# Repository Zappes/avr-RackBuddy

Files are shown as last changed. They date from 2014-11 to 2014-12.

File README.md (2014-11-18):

Der RackBuddy
============

Was isses?
-------------

Der RackBuddy ist ein Dingsbums für mein Serverrack, das Temperaturen misst, sie auf 7-Segment-Anzeigen ausgibt und per USB an den Rechner meldet.

Zum RackBuddy gibt es auch ein paar Videos, und zwar hier:

 - [Playlist bei Youtube](http://www.youtube.com/playlist?list=PLFFlJlvZ--PkYDAD19FQtcRBbY8yCnrR-)

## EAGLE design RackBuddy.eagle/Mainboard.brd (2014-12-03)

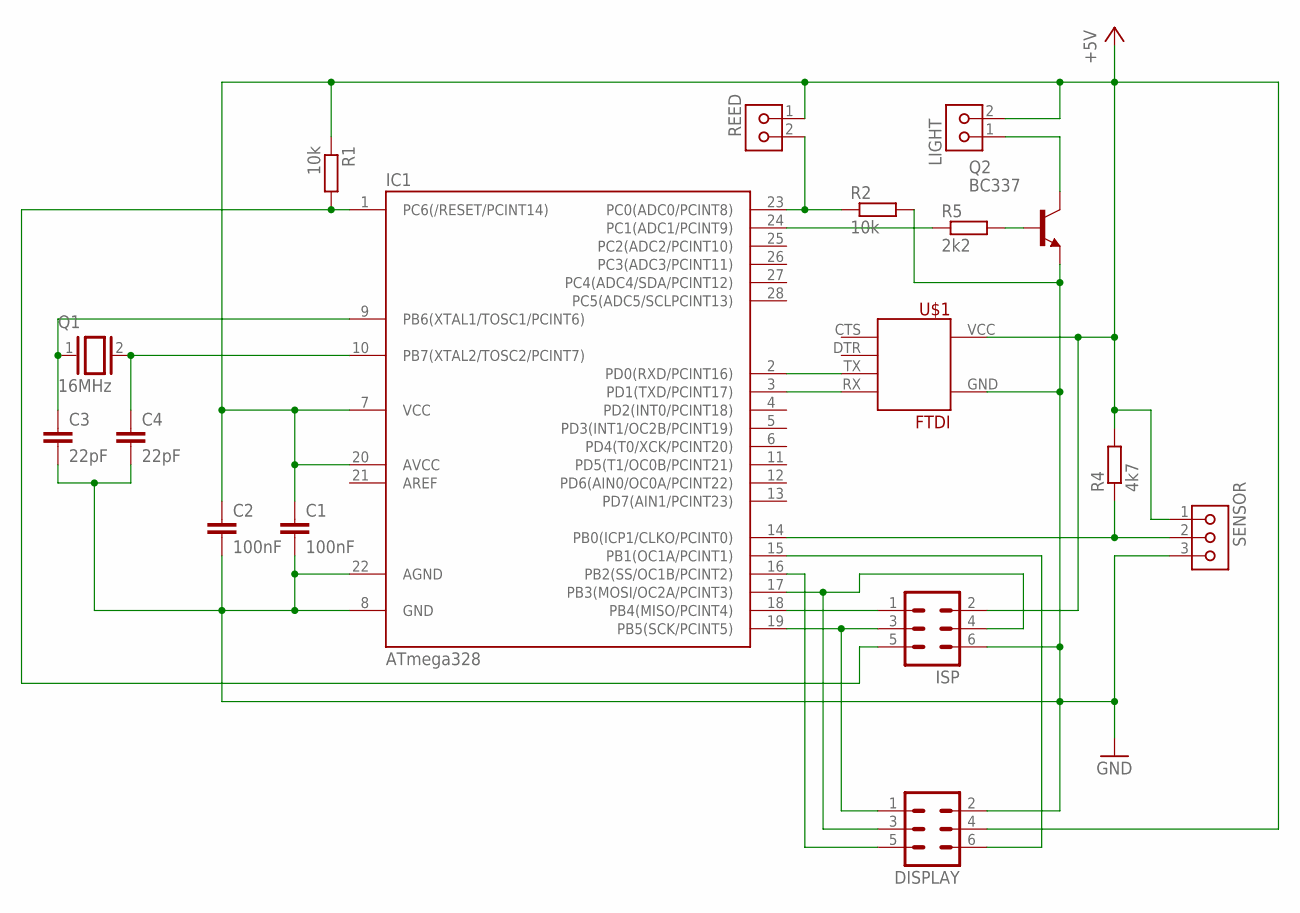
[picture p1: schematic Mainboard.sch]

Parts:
C1: 100nF; C050-025X075
C2: 100nF; C025-025X050
C3, C4: 22pF; C025-025X050
DISPLAY: ML6
IC1: ATmega328; DIL28-3
ISP: ML6
LIGHT: KK2VSQ; KK-V-2-SQ
Q1: 16MHz; QS
Q2: BC337; TO92-STRAIGHT-0.254
R1: 10k; 0207/10
R2: 10k; 0204V
R4: 4k7; 0204/7
R5: 2k2; 0204/7
REED: KK2VSQ; KK-V-2-SQ
SENSOR: KK3V; KK-V-3
U$1: FTDI; FTDI-1

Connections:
+5V: C1.1, C2.1, DISPLAY.4, IC1.7 (VCC), IC1.20 (AVCC), ISP.2, LIGHT.2, R1.1, R4.2, REED.1, SENSOR.1, U$1.VCC (+5V)
GND: C1.2, C2.2, C3.2, C4.2, DISPLAY.2, IC1.8 (GND), IC1.22 (AGND), ISP.6, Q2.3 (E), R2.2, SENSOR.3, U$1.GND
unnamed: Q2.2 (B), R5.2
unnamed: IC1.24 (PC1(ADC1/PCINT9)), R5.1
unnamed: IC1.2 (PD0(RXD/PCINT16)), U$1.TX
unnamed: IC1.3 (PD1(TXD/PCINT17)), U$1.RX
unnamed: C3.1, IC1.9 (PB6(XTAL1/TOSC1/PCINT6)), Q1.1
unnamed: C4.1, IC1.10 (PB7(XTAL2/TOSC2/PCINT7)), Q1.2
unnamed: DISPLAY.3, IC1.17 (PB3(MOSI/OC2A/PCINT3)), ISP.4
unnamed: IC1.1 (PC6(/RESET/PCINT14)), ISP.5, R1.2
unnamed: IC1.23 (PC0(ADC0/PCINT8)), R2.1, REED.2
unnamed: IC1.14 (PB0(ICP1/CLKO/PCINT0)), R4.1, SENSOR.2
unnamed: LIGHT.1, Q2.1 (C)
unnamed: DISPLAY.5, IC1.16 (PB2(SS/OC1B/PCINT2))
unnamed: IC1.18 (PB4(MISO/PCINT4)), ISP.1
unnamed: DISPLAY.1, IC1.19 (PB5(SCK/PCINT5)), ISP.3
unnamed: DISPLAY.6, IC1.15 (PB1(OC1A/PCINT1))

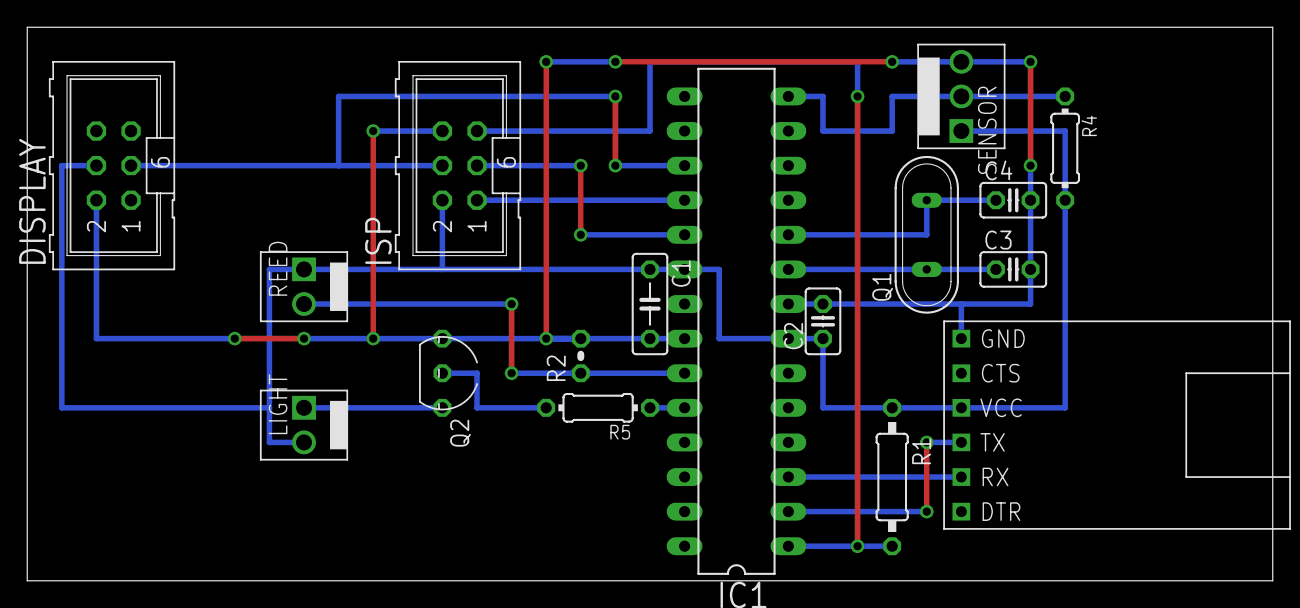
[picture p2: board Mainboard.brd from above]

Board: 3 copper layers, 91.4 x 40.6 mm, 17 parts (0 on the bottom side), 17 nets.

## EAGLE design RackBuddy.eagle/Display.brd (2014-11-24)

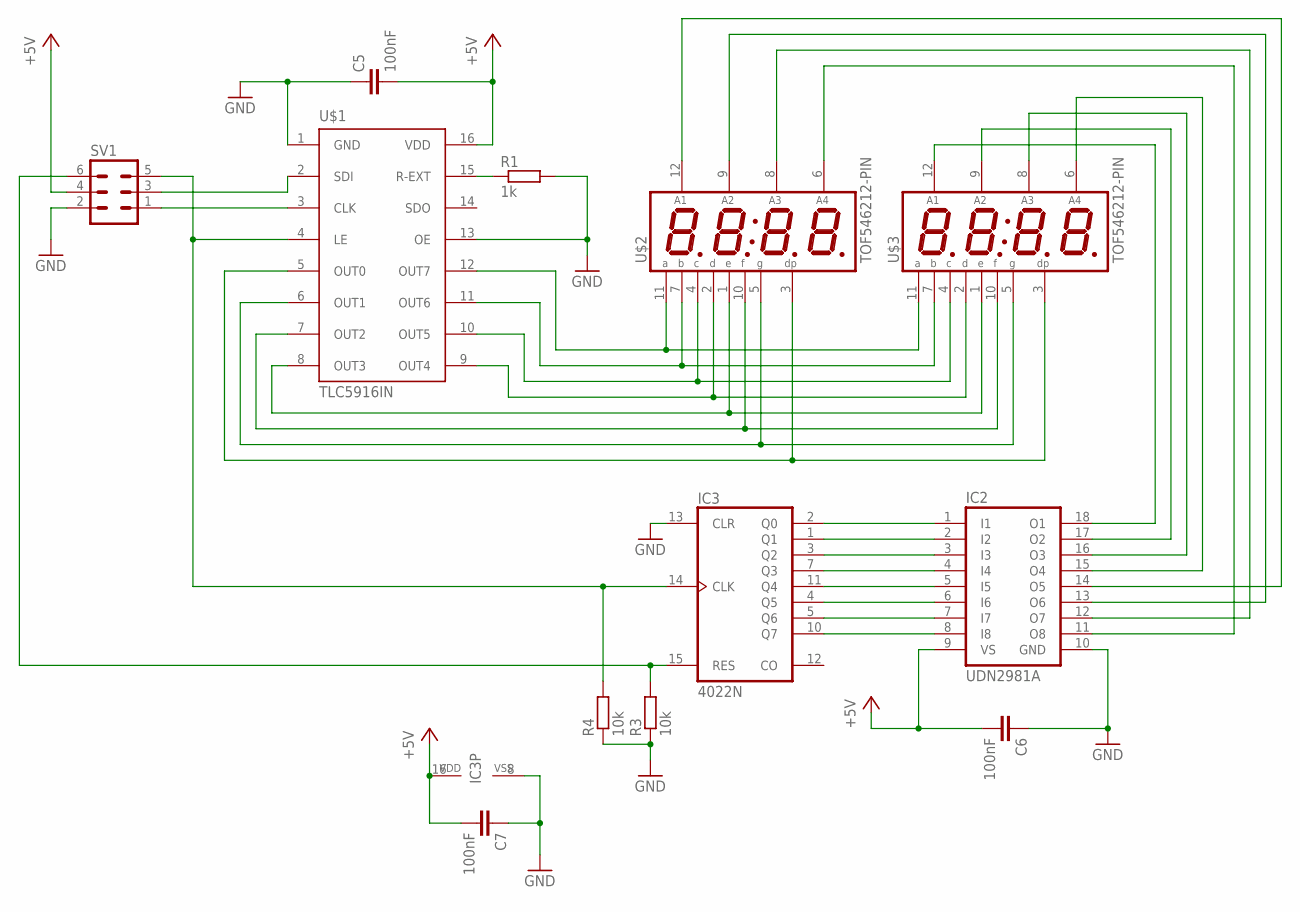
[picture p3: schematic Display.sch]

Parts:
C5, C6, C7: 100nF; C025-024X044
IC2: UDN2981A; DIL18
IC3: 4022N; DIL16
R1: 1k; 0204/7
R3, R4: 10k; 0204V
SV1: ML6L
U$1: TLC5916IN; DIL16
U$2, U$3: TOF546212-PIN; TOF5462*

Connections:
+5V: C5.2, C6.2, C7.2, IC2.9 (VS), IC3.16 (VDD), SV1.4, U$1.16 (VDD)
CLOCK: SV1.1, U$1.3 (CLK)
DATA: SV1.3, U$1.2 (SDI)
GND: C5.1, C6.1, C7.1, IC2.10 (GND), IC3.8 (VSS), IC3.13 (CLR), R1.2, R3.1, R4.1, SV1.2, U$1.1 (GND), U$1.13 (OE)
LATCH: IC3.14 (CLK), R4.2, SV1.5, U$1.4 (LE)
unnamed: U$1.11 (OUT6), U$2.7 (B), U$3.7 (B)
unnamed: IC2.17 (O2), U$3.9 (A2)
unnamed: U$1.10 (OUT5), U$2.4 (C), U$3.4 (C)
unnamed: U$1.9 (OUT4), U$2.2 (D), U$3.2 (D)
unnamed: R1.1, U$1.15 (R-EXT)
unnamed: U$1.8 (OUT3), U$2.1 (E), U$3.1 (E)
unnamed: U$1.7 (OUT2), U$2.10 (F), U$3.10 (F)
unnamed: U$1.6 (OUT1), U$2.5 (G), U$3.5 (G)
unnamed: U$1.5 (OUT0), U$2.3 (DP), U$3.3 (DP)
unnamed: IC2.1 (I1), IC3.2 (Q0)
unnamed: IC2.2 (I2), IC3.1 (Q1)
unnamed: IC2.3 (I3), IC3.3 (Q2)
unnamed: IC2.4 (I4), IC3.7 (Q3)
unnamed: IC2.5 (I5), IC3.11 (Q4)
unnamed: IC2.6 (I6), IC3.4 (Q5)
unnamed: IC2.7 (I7), IC3.5 (Q6)
unnamed: IC2.8 (I8), IC3.10 (Q7)
unnamed: IC2.18 (O1), U$3.12 (A1)
unnamed: IC2.14 (O5), U$2.12 (A1)
unnamed: U$1.12 (OUT7), U$2.11 (A), U$3.11 (A)
unnamed: IC2.13 (O6), U$2.9 (A2)
unnamed: IC2.16 (O3), U$3.8 (A3)
unnamed: IC2.12 (O7), U$2.8 (A3)
unnamed: IC2.15 (O4), U$3.6 (A4)
unnamed: IC2.11 (O8), U$2.6 (A4)
RESET: IC3.15 (RES), R3.2, SV1.6

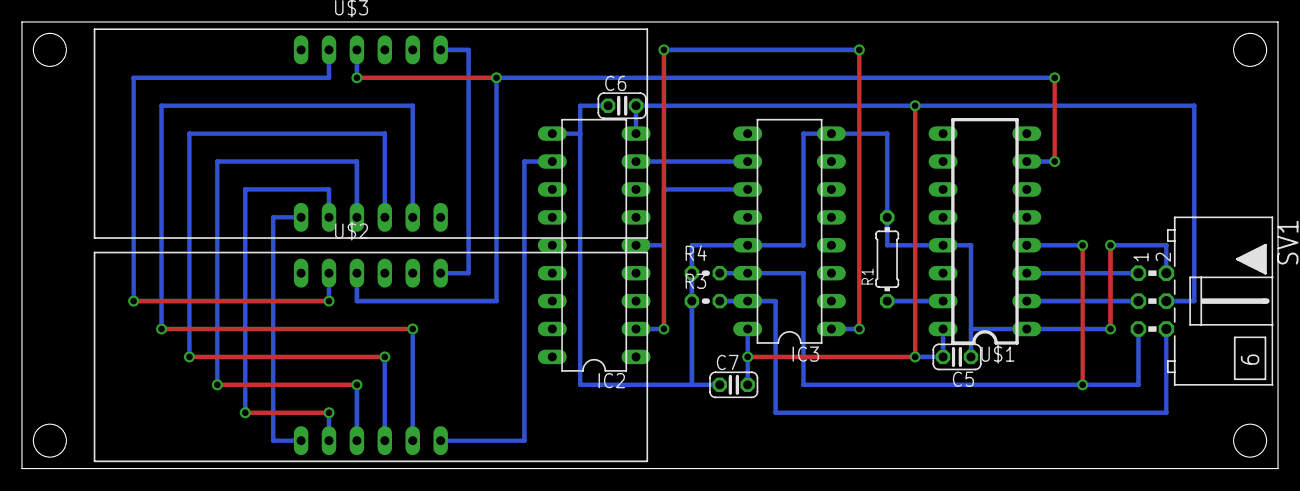
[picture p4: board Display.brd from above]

Board: 2 copper layers, 114.3 x 40.6 mm, 12 parts (0 on the bottom side), 31 nets.

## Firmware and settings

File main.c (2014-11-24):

/*
 * Controller code for a device that reads analog sensor values and sleeps
 * while it isn't used. Check the README at Github for more information.
 *
 * Written by Gregor Ottmann, https://github.com/Zappes
 */
#include <avr/io.h>
#include <avr/interrupt.h>
#include <util/delay.h>
#include <stdio.h>

#include "lib/display.h"
#include "lib/uart.h"
#include "lib/onewire.h"
#include "lib/ds18x20.h"
#include "lib/doorlight.h"

// this is something I wanted to do in code for a long time, but at work it seemed ill-advised to do so:
// PENIS PENIS PENIS PENIS PENIS PENIS

char dc_buffer[10];
uint16_t temp_values[2];

#define TEMP_DELAY 20000;
volatile uint16_t temp_counter = 0;
volatile uint8_t temp_do_measure = 1;

uint8_t door_status = 255;

char buffer[64];

void init_comm() {
	uart_init(UART_BAUD_SELECT(9600, F_CPU));
}

/**
 * Sets up a timer interrupt that will be called every 8192 clock cycles, i.e. with
 * about 2kHz.
 */
void init_main_loop() {
	cli();

	// CTC with OCR0A as TOP
	TCCR0A = (1 << WGM01);

	// clk_io/1024 (From prescaler)
	TCCR0B = ((1 << CS02) | (1 << CS00));

	// Generate an interrupt every 8192 clock cycles
	OCR0A = 7;

	// Enable Timer/Counter0 Compare Match A interrupt
	TIMSK0 |= (1 << OCIE0A);

	sei();
}

ISR(TIMER0_COMPA_vect) {
	display_refresh();

	// enable the fucking temeperature sensor every TEMP_DELAY interrupts, i.e. every TEMP_DELAY/4000 seconds
	if(temp_counter-- == 0) {
		temp_do_measure = 1;
		temp_counter = TEMP_DELAY;
	}
}

uint8_t gSensorIDs[2][8] = { { 0x10, 0xA1, 0x3E, 0xE8, 0x02, 0x08, 0x00, 0xDA },
		{ 0x10, 0xA0, 0x12, 0xE8, 0x02, 0x08, 0x00, 0x34 } };

int main(void) {
	init_display();
	init_comm();
	init_doorlight();
	init_main_loop();

	int16_t decicelsius;

#ifndef OW_ONE_BUS
	ow_set_bus(&PINB,&PORTB,&DDRB,PB0);
#endif

	while (1) {

		if(temp_do_measure) {
			if (DS18X20_start_meas( DS18X20_POWER_EXTERN, NULL) == DS18X20_OK) {
				_delay_ms( DS18B20_TCONV_12BIT);
				for (int i = 0; i < 2; i++) {
					if (DS18X20_read_decicelsius(&gSensorIDs[i][0],&decicelsius) == DS18X20_OK) {
						temp_values[i] = decicelsius;
					} else {
						temp_values[i] = 0;
					}
				}
			}
			else {
				uart_puts("Le Fuck.\r\n");
			}

			DS18X20_format_from_decicelsius( temp_values[0], dc_buffer, 10 );
			sprintf(buffer, "Sensor #%d=%s  ", 0, dc_buffer);
			uart_puts(buffer);
			DS18X20_format_from_decicelsius( temp_values[1], dc_buffer, 10 );
			sprintf(buffer, "Sensor #%d=%s\r\n", 1, dc_buffer);
			uart_puts(buffer);

			display_values(temp_values[0] / 10, (temp_values[0] % 10) * 10, temp_values[1] / 10, (temp_values[1] % 10) * 10);
			temp_do_measure = 0;
		}

		if(door_status != dl_door_closed()) {
			door_status = dl_door_closed();
			dl_set_light_status(door_status ? 0 : 1);

			sprintf(buffer, "Door status: %s\r\n", dl_door_closed() ? "closed" : "open");
			uart_puts(buffer);
		}
	}
	return 0;
}

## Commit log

2014-11-18 Added README
    [Display.sch]
2014-11-18 Added stuff, updated .gitignore
    [Display.brd]
2014-11-24 Added door light and schematics
    [Display.brd, Mainboard.sch]
2014-12-03 An den Plänen gearbeitet
    [Mainboard.brd, Mainboard.sch]
